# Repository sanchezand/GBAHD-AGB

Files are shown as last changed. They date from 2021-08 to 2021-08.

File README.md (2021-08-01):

# GBAHD-AGB Motherboard
This is a replacement AGB motherboard shield for the [gbaHD project](https://github.com/zwenergy/gbaHD).  
- The aim is to remove the CPU and RAM from an original AGB motherboard and place them in this new board.  
- Uses an MCU to connect a classic controller.  
- Has a cartridge slot with a switch to detect DMG/CGB games and switch voltages.
- Has a power switch circuitry to replace Spartan Edge switch.
- Has a better footprint for 3D printed cases

## Issues
- NOT TESTED YET
- Cart sensor switch might need to be changed
- Cart sensor switch footprint might be wrong.
- Clock might need to be rerouted.
- Link port might need to be rerouted
- No 3D printed case (yet)

## Contributing
I am **NOT** an electrical engineer. Take this as a hobby project from a software engineer's attempt at something cool. If you wish to contribute, see something wrong or want to add a feature please make a pull request or leave an issue!

## BOM
Add this later...

## Programming the MCU
**FIRMWARE NOT YET WRITTEN** (following instructions still work)

In order to program the MCU, you need an arduino to use as ISP.  
Use the following image to wire up an arduino to the board to program it.  
**I would also recomend not programming it while seated in the FPGA board.**
PCB Wireup  
After wiring the board, follow this tutorial to flash the bootloader and the sketch to the board.  
[ICSP Tutorial](https://www.arduino.cc/en/pmwiki.php?n=Tutorial/ArduinoISP)  
  
The Arduino code requires the [NintendoExtensionCtrl](https://github.com/dmadison/NintendoExtensionCtrl) library.

## Credits
This project would've not existed if it werent for people with real electrical engineering knowledge!
- ARCADETV - (Their AGB schematics seem to have dissapeared)
- Derek F - [GBA-2 Go](https://hackaday.io/project/169998-gba-2-go)
- Zwenergy - [GBAHD Creator](https://github.com/zwenergy/gbaHD)
- dmadison - [Nintendo Controller Libraries](https://github.com/dmadison/NintendoExtensionCtrl)

## Images
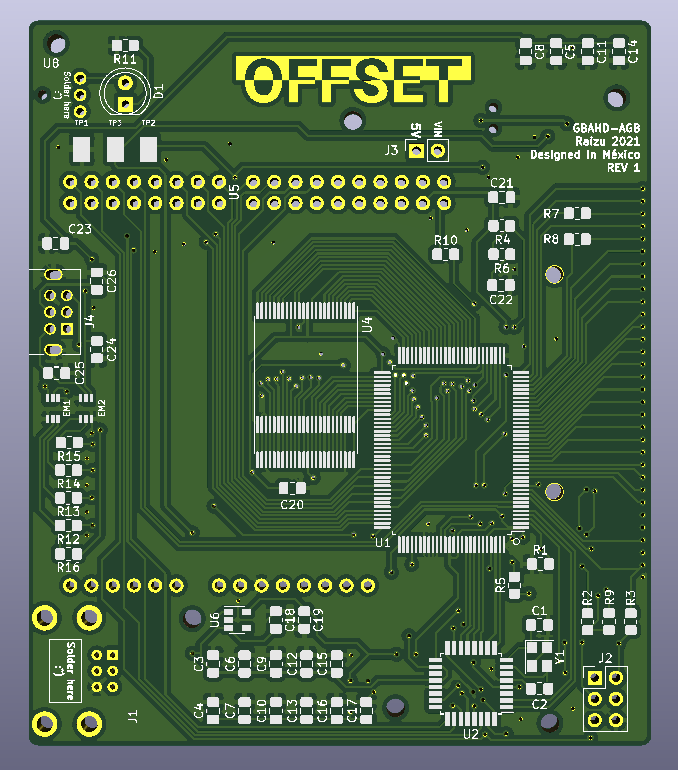
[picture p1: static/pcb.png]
PCB


## LICENSE
This documentation describes Open Hardware and is licensed under the CERN OHL v. 1.2.
You may redistribute and modify this documentation under the terms of the CERN OHL v.1.2. (http://ohwr.org/cernohl). This documentation is distributed WITHOUT ANY EXPRESS OR IMPLIED WARRANTY, INCLUDING OF MERCHANTABILITY, SATISFACTORY QUALITY AND FITNESS FOR A PARTICULAR PURPOSE. Please see the CERN OHL v.1.2 for applicable conditions.

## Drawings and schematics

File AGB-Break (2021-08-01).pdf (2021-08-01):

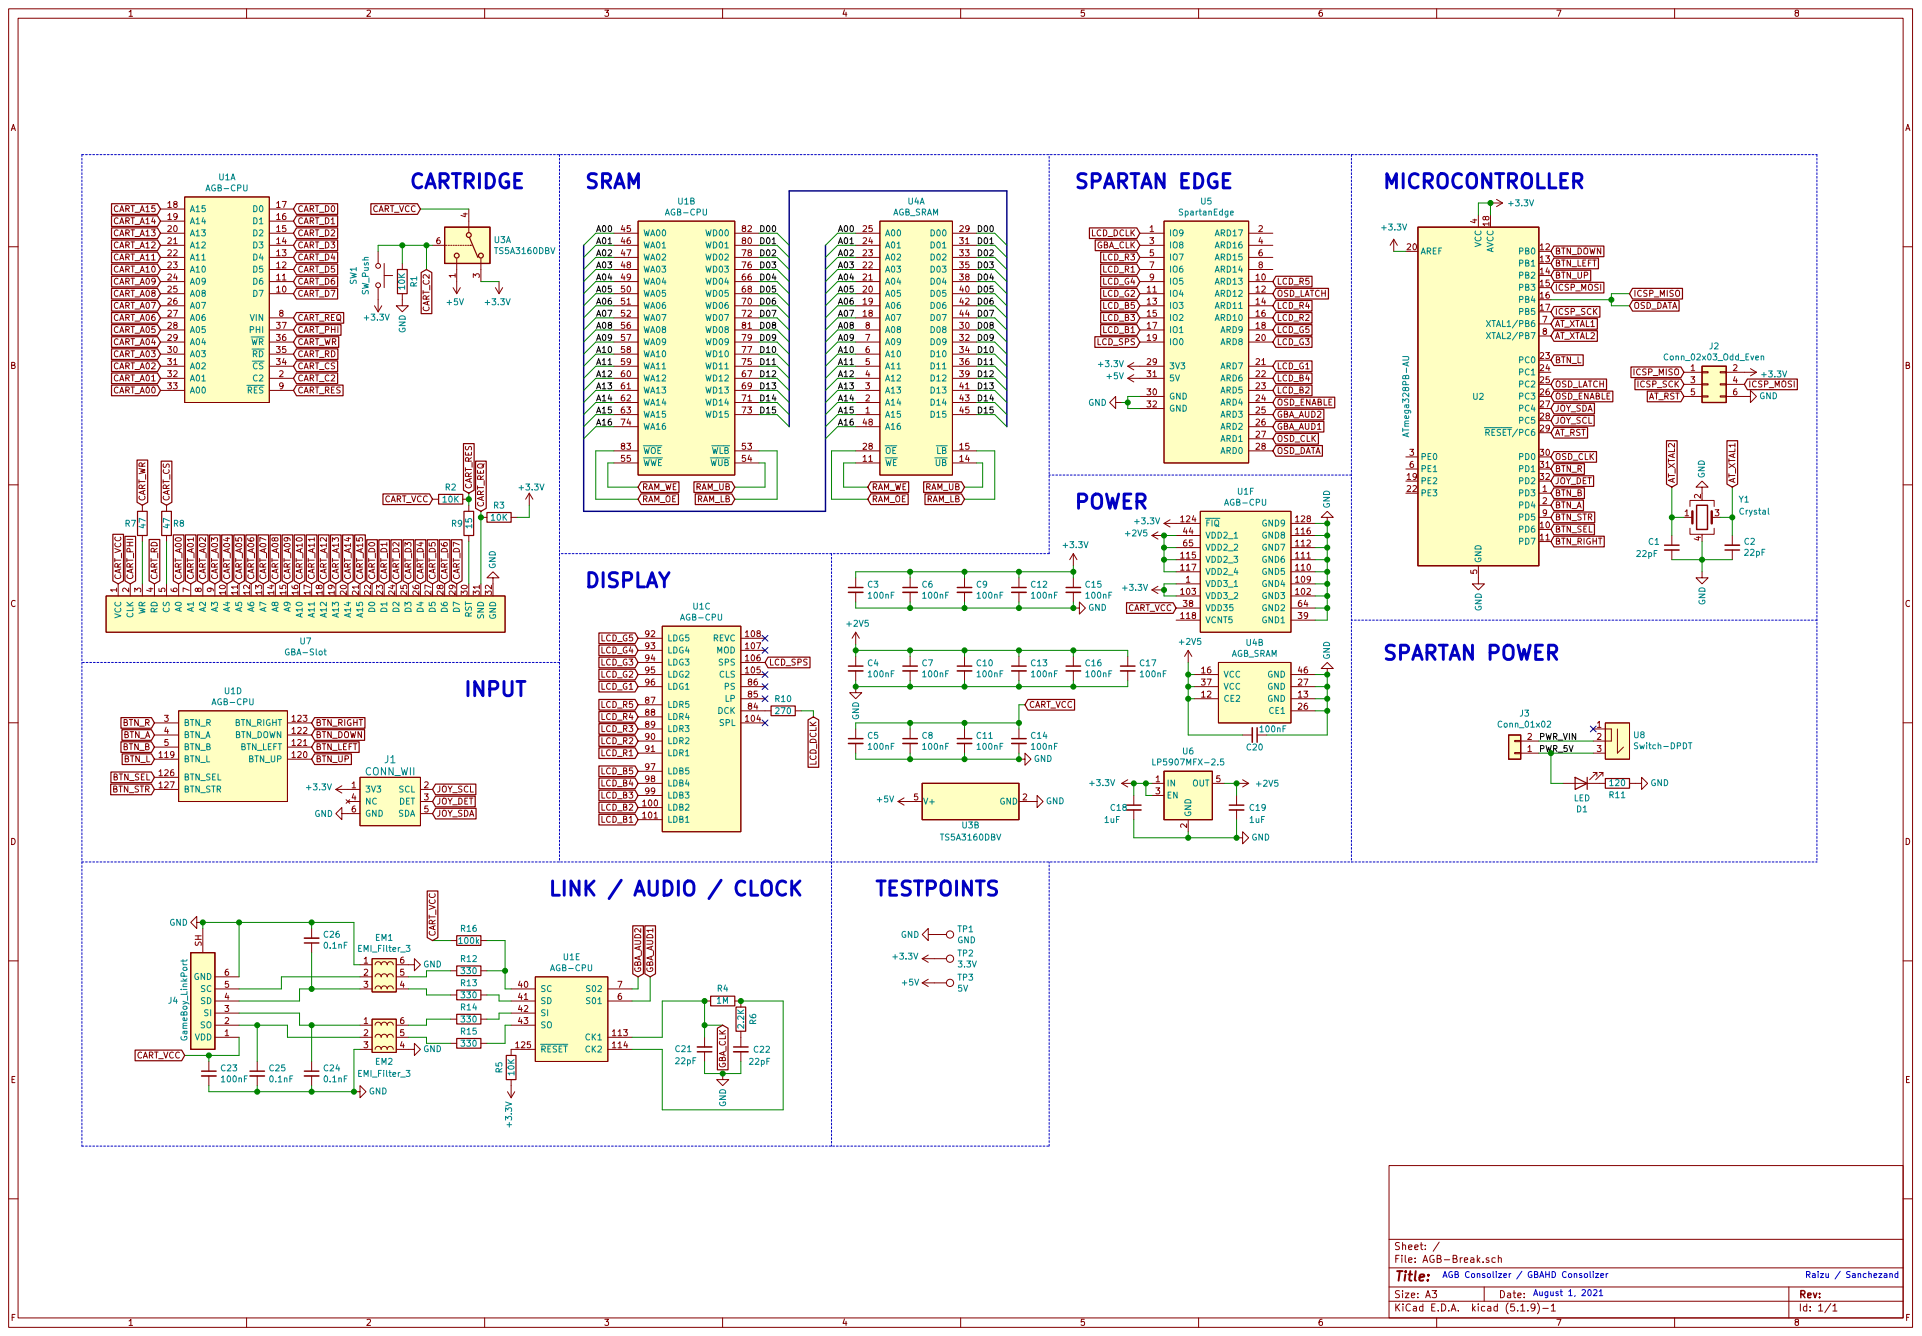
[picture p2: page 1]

9 U7 GBA-Slot VDD3_1 1 GND3 102 VDD3_2 103 GND4 109 GND5 110 GND6 111 GND7 112 VDD2_3 115 GND8 116 VDD2_4 117 VCNT5 118 FIQ 124 GND9 128 VDD35 38 GND1 39 VDD2_1 44 GND2 64 VDD2_2 65 U1F AGB-CPU

DISPLAY | | 100nF R3

3 RST 30 SND 31 GND 32 RD

Raizu / Sanchezand SPARTAN POWER

LINK / AUDIO / CLOCK | TESTPOINTS TP2 +3.3V 3.3V TP3 5V

2 | 5 R15

Id: 1/1 Title: File: AGB-Break.sch Sheet: /

AGB Consolizer / GBAHD Consolizer

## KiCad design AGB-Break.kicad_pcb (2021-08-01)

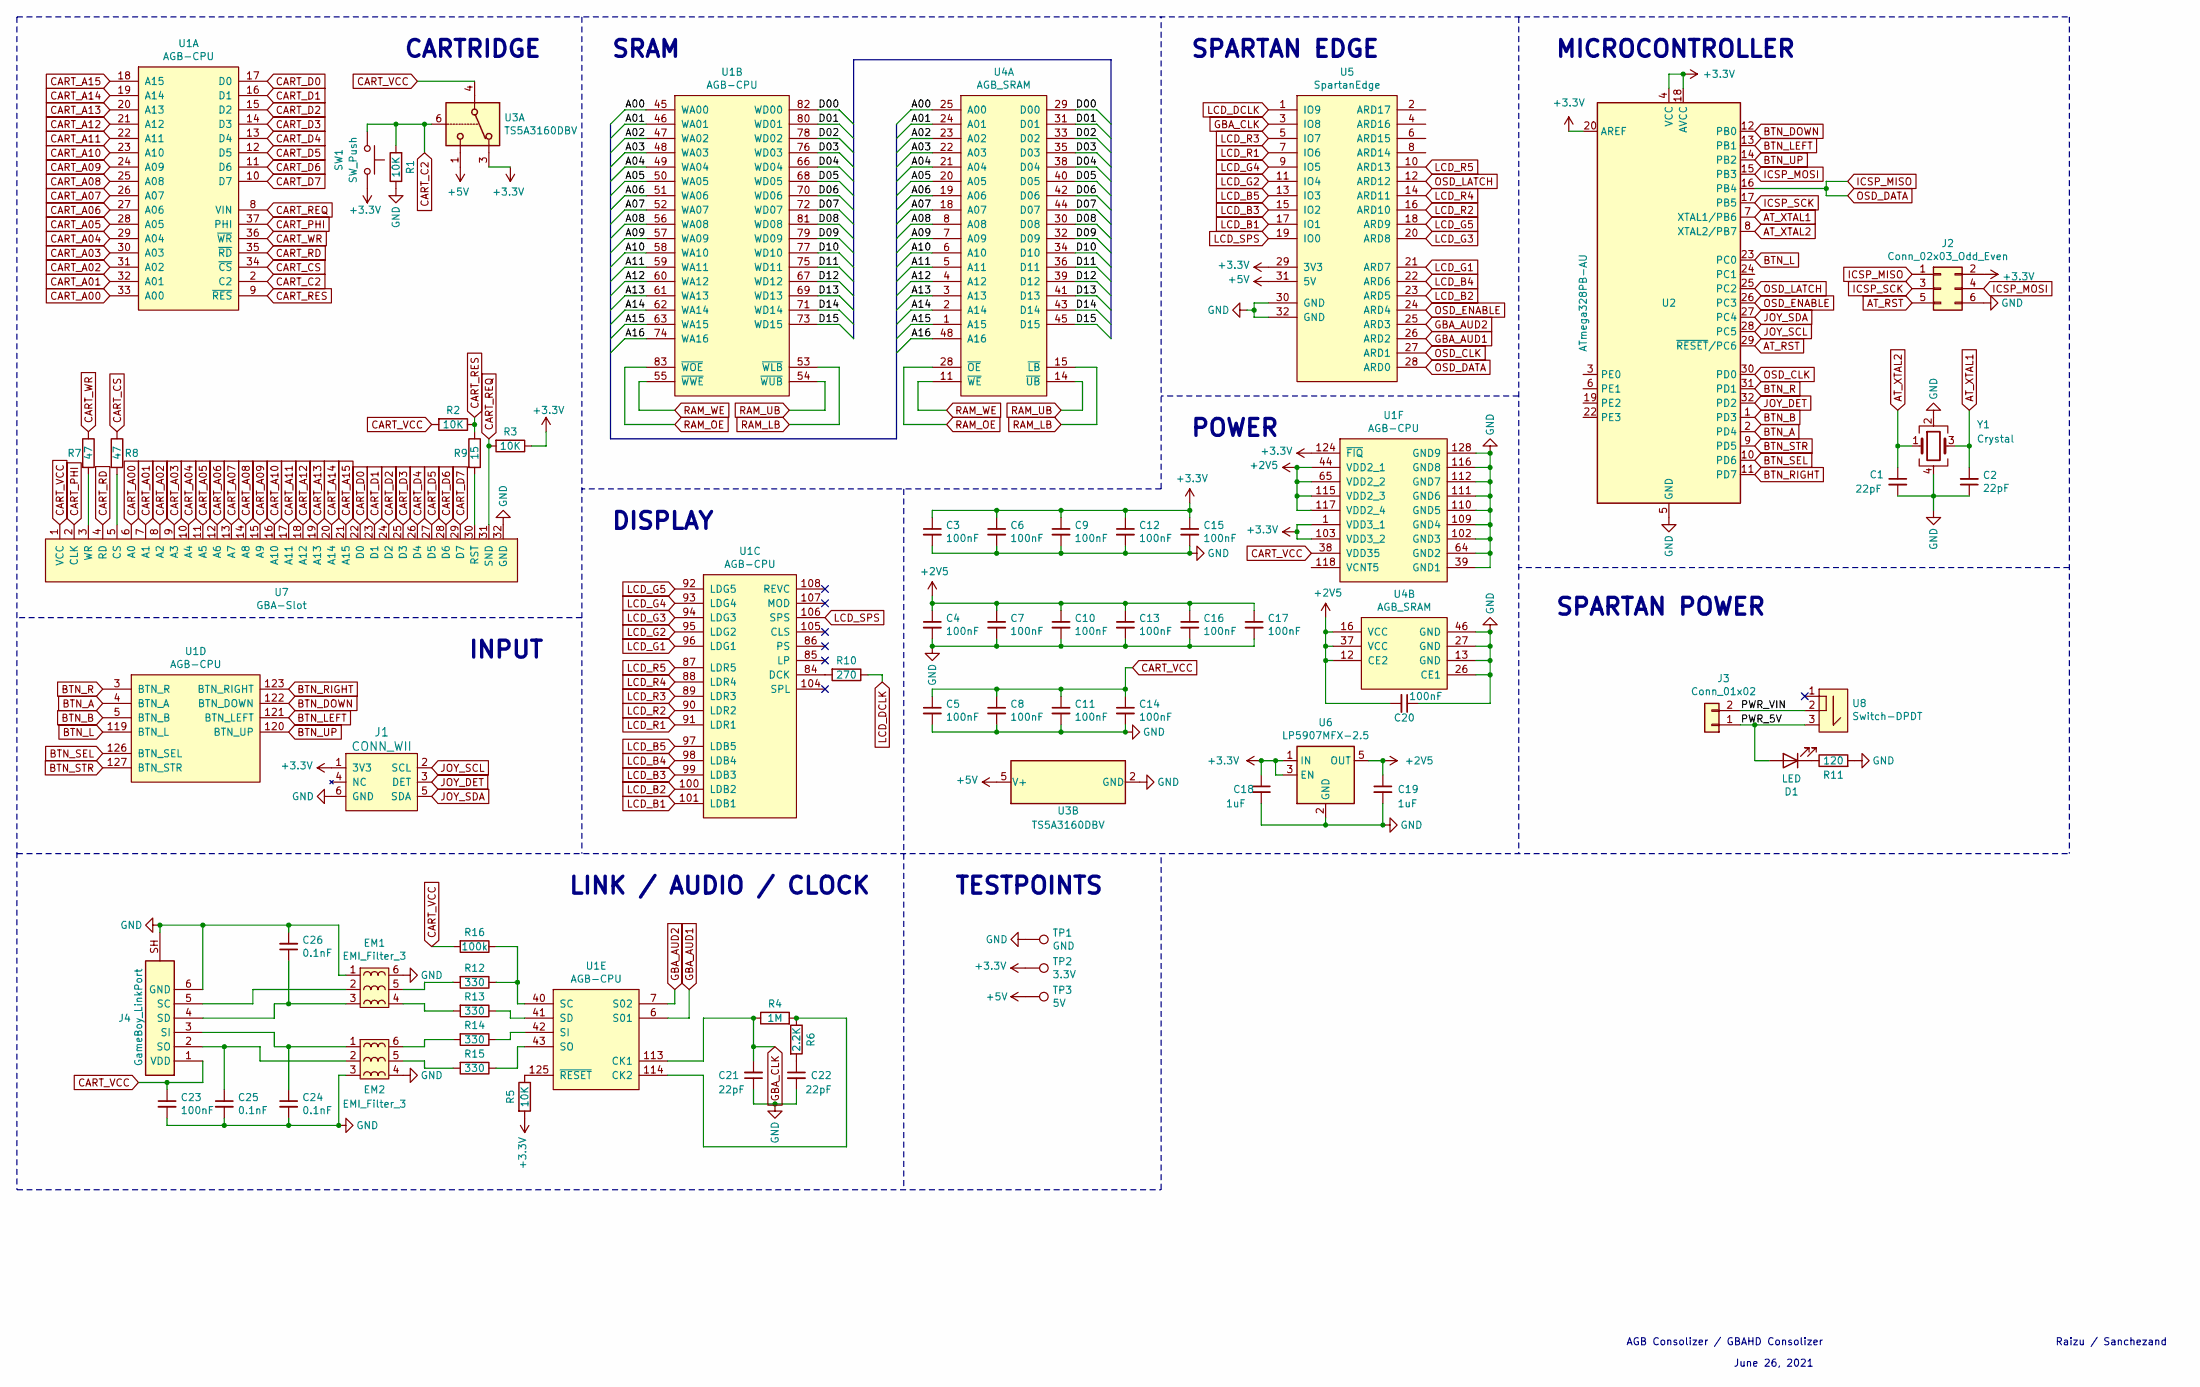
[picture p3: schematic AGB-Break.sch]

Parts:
C1, C2, C21, C22: 22pF; C_0805_2012Metric_Pad1.18x1.45mm_HandSolder
C3, C4, C5, C6, C7, C8, C9, C10, C11, C12, C13, C14, C15, C16, C17, C20, C23: 100nF; C_0805_2012Metric_Pad1.18x1.45mm_HandSolder
C18, C19: 1uF; C_0805_2012Metric_Pad1.18x1.45mm_HandSolder
C24, C25, C26: 0.1nF; C_0805_2012Metric_Pad1.18x1.45mm_HandSolder
D1: LED; LED_D5.0mm_FlatTop
EM1, EM2: EMI_Filter_3; Inductor-1008-3P
J1: CONN_WII
J2: Conn_02x03_Odd_Even; PinHeader_2x03_P2.54mm_Vertical
J3: Conn_01x02; PinSocket_1x02_P2.54mm_Vertical
J4: GameBoy_LinkPort; GameBoy_LinkPort_MGB_Horizontal
R1, R2, R3, R5: 10K; R_0805_2012Metric_Pad1.20x1.40mm_HandSolder
R4: 1M; R_0805_2012Metric_Pad1.20x1.40mm_HandSolder
R6: 2.2K; R_0805_2012Metric_Pad1.20x1.40mm_HandSolder
R7, R8: 47; R_0805_2012Metric_Pad1.20x1.40mm_HandSolder
R9: 15; R_0805_2012Metric_Pad1.20x1.40mm_HandSolder
R10: 270; R_0805_2012Metric_Pad1.20x1.40mm_HandSolder
R11: 120; R_0805_2012Metric_Pad1.20x1.40mm_HandSolder
R12, R13, R14, R15: 330; R_0805_2012Metric_Pad1.20x1.40mm_HandSolder
R16: 100k; R_0805_2012Metric_Pad1.20x1.40mm_HandSolder
SW1: SW_Push; Switch_K5-1617SA-01
TP1: GND; SOLDER_PAD
TP2: 3.3V; SOLDER_PAD
TP3: 5V; SOLDER_PAD
U1: AGB-CPU
U2: ATmega328PB-AU; TQFP-32_7x7mm_P0.8mm
U3: TS5A3160DBV; SOT-23-6
U4: AGB_SRAM
U5: SpartanEdge; SpartanEdge_Shield
U6: LP5907MFX-2.5; SOT-23-5
U7: GBA-Slot; GBA_CONNECTOR
U8: Switch-DPDT; XKB_XKB5858-Z-C
Y1: Crystal; Crystal_SMD_3225-4Pin_3.2x2.5mm

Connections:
+2V5: C4.1, C7.1, C10.1, C13.1, C16.1, C17.1, C19.1, C20.2, U1.44 (VDD2_1), U1.65 (VDD2_2), U1.115 (VDD2_3), U1.117 (VDD2_4), U4.12 (CE2), U4.16 (VCC), U4.37 (VCC), U6.5 (OUT)
+3V3: C3.1, C6.1, C9.1, C12.1, C15.1, C18.1, J1.1 (3V3), J2.2, R3.1, R5.2, SW1.2, TP2.1, U1.1 (VDD3_1), U1.103 (VDD3_2), U1.124 (~FIQ), U2.4 (VCC), U2.18 (AVCC), U2.20 (AREF), U3.3, U5.29 (3V3), U6.1 (IN), U6.3 (EN)
+5V: TP3.1, U3.1, U3.5 (V+), U5.31 (5V)
/A00: U1.45 (WA00), U4.25 (A00)
/A01: U1.46 (WA01), U4.24 (A01)
/A02: U1.47 (WA02), U4.23 (A02)
/A03: U1.48 (WA03), U4.22 (A03)
/A04: U1.49 (WA04), U4.21 (A04)
/A05: U1.50 (WA05), U4.20 (A05)
/A06: U1.51 (WA06), U4.19 (A06)
/A07: U1.52 (WA07), U4.18 (A07)
/A08: U1.56 (WA08), U4.8 (A08)
/A09: U1.57 (WA09), U4.7 (A09)
/A10: U1.58 (WA10), U4.6 (A10)
/A11: U1.59 (WA11), U4.5 (A11)
/A12: U1.60 (WA12), U4.4 (A12)
/A13: U1.61 (WA13), U4.3 (A13)
/A14: U1.62 (WA14), U4.2 (A14)
/A15: U1.63 (WA15), U4.1 (A15)
/A16: U1.74 (WA16), U4.48 (A16)
/D00: U1.82 (WD00), U4.29 (D00)
/D01: U1.80 (WD01), U4.31 (D01)
/D02: U1.78 (WD02), U4.33 (D02)
/D03: U1.76 (WD03), U4.35 (D03)
/D04: U1.66 (WD04), U4.38 (D04)
/D05: U1.68 (WD05), U4.40 (D05)
/D06: U1.70 (WD06), U4.42 (D06)
/D07: U1.72 (WD07), U4.44 (D07)
/D08: U1.81 (WD08), U4.30 (D08)
/D09: U1.79 (WD09), U4.32 (D09)
/D10: U1.77 (WD10), U4.34 (D10)
/D11: U1.75 (WD11), U4.36 (D11)
/D12: U1.67 (WD12), U4.39 (D12)
/D13: U1.69 (WD13), U4.41 (D13)
/D14: U1.71 (WD14), U4.43 (D14)
/D15: U1.73 (WD15), U4.45 (D15)
/PWR_5V: D1.2 (A), J3.1, U8.3
/PWR_VIN: J3.2, U8.2
AT_RST: J2.5, U2.29 (~RESET~/PC6)
AT_XTAL1: C2.2, U2.7 (XTAL1/PB6), Y1.3
AT_XTAL2: C1.1, U2.8 (XTAL2/PB7), Y1.1
BTN_A: U1.4 (BTN_A), U2.2 (PD4)
BTN_B: U1.5 (BTN_B), U2.1 (PD3)
BTN_DOWN: U1.122 (BTN_DOWN), U2.12 (PB0)
BTN_L: U1.119 (BTN_L), U2.23 (PC0)
BTN_LEFT: U1.121 (BTN_LEFT), U2.13 (PB1)
BTN_R: U1.3 (BTN_R), U2.31 (PD1)
BTN_RIGHT: U1.123 (BTN_RIGHT), U2.11 (PD7)
BTN_SEL: U1.126 (BTN_SEL), U2.10 (PD6)
BTN_STR: U1.127 (BTN_STR), U2.9 (PD5)
BTN_UP: U1.120 (BTN_UP), U2.14 (PB2)
CART_A00: U1.33 (A00), U7.6 (A0)
CART_A01: U1.32 (A01), U7.7 (A1)
CART_A02: U1.31 (A02), U7.8 (A2)
CART_A03: U1.30 (A03), U7.9 (A3)
CART_A04: U1.29 (A04), U7.10 (A4)
CART_A05: U1.28 (A05), U7.11 (A5)
CART_A06: U1.27 (A06), U7.12 (A6)
CART_A07: U1.26 (A07), U7.13 (A7)
CART_A08: U1.25 (A08), U7.14 (A8)
CART_A09: U1.24 (A09), U7.15 (A9)
CART_A10: U1.23 (A10), U7.16 (A10)
CART_A11: U1.22 (A11), U7.17 (A11)
CART_A12: U1.21 (A12), U7.18 (A12)
CART_A13: U1.20 (A13), U7.19 (A13)
CART_A14: U1.19 (A14), U7.20 (A14)
CART_A15: U1.18 (A15), U7.21 (A15)
CART_C2: R1.2, SW1.1, U1.2 (C2), U3.6
CART_CS: R8.1, U1.34 (~CS)
CART_D0: U1.17 (D0), U7.22 (D0)
CART_D1: U1.16 (D1), U7.23 (D1)
CART_D2: U1.15 (D2), U7.24 (D2)
CART_D3: U1.14 (D3), U7.25 (D3)
CART_D4: U1.13 (D4), U7.26 (D4)
CART_D5: U1.12 (D5), U7.27 (D5)
CART_D6: U1.11 (D6), U7.28 (D6)
CART_D7: U1.10 (D7), U7.29 (D7)
CART_PHI: U1.37 (PHI), U7.2 (CLK~)
CART_RD: U1.35 (~RD), U7.4 (RD)
CART_REQ: R3.2, U1.8 (VIN), U7.31 (SND)
CART_RES: R2.1, R9.1, U1.9 (~RES)
CART_VCC: C5.1, C8.1, C11.1, C14.1, C23.1, J4.1 (VDD), R2.2, R16.2, U1.38 (VDD35), U3.4, U7.1 (VCC)
CART_WR: R7.1, U1.36 (~WR)
GBA_AUD1: U1.6 (S01), U5.26 (ARD2)
GBA_AUD2: U1.7 (S02), U5.25 (ARD3)
GBA_CLK: C21.2, R4.1, U1.113 (CK1), U5.3 (IO8)
GND: C1.2, C2.1, C3.2, C4.2, C5.2, C6.2, C7.2, C8.2, C9.2, C10.2, C11.2, C12.2, C13.2, C14.2, C15.2, C16.2, C17.2, C18.2, C19.2, C20.1, C21.1, C22.2, C23.2, C24.2, C25.2, C26.2, EM1.1, EM1.6, EM2.3, EM2.4, J1.6 (GND), J2.6, J4.6 (GND), J4.SH, R1.1, R11.2, TP1.1, U1.39 (GND1), U1.64 (GND2), U1.102 (GND3), U1.109 (GND4), U1.110 (GND5), U1.111 (GND6), U1.112 (GND7), U1.116 (GND8), U1.128 (GND9), U2.5 (GND), U2.21 (GND), U3.2 (GND), U4.13 (GND), U4.26 (CE1), U4.27 (GND), U4.46 (GND), U5.30 (GND), U5.32 (GND), U6.2 (GND), U7.32 (GND), Y1.2, Y1.4
ICSP_MISO: J2.1, U2.16 (PB4), U5.28 (ARD0)
ICSP_MOSI: J2.4, U2.15 (PB3)
ICSP_SCK: J2.3, U2.17 (PB5)
JOY_DET: J1.3 (DET), U2.32 (PD2)
JOY_SCL: J1.2 (SCL), U2.28 (PC5)
JOY_SDA: J1.5 (SDA), U2.27 (PC4)
LCD_B1: U1.101 (LDB1), U5.17 (IO1)
LCD_B2: U1.100 (LDB2), U5.23 (ARD5)
LCD_B3: U1.99 (LDB3), U5.15 (IO2)
LCD_B4: U1.98 (LDB4), U5.22 (ARD6)
LCD_B5: U1.97 (LDB5), U5.13 (IO3)
LCD_DCLK: R10.1, U5.1 (IO9)
LCD_G1: U1.96 (LDG1), U5.21 (ARD7)
LCD_G2: U1.95 (LDG2), U5.11 (IO4)
LCD_G3: U1.94 (LDG3), U5.20 (ARD8)
LCD_G4: U1.93 (LDG4), U5.9 (IO5)
LCD_G5: U1.92 (LDG5), U5.18 (ARD9)
LCD_R1: U1.91 (LDR1), U5.7 (IO6)
LCD_R2: U1.90 (LDR2), U5.16 (ARD10)
LCD_R3: U1.89 (LDR3), U5.5 (IO7)
LCD_R4: U1.88 (LDR4), U5.14 (ARD11)
LCD_R5: U1.87 (LDR5), U5.10 (ARD13)
LCD_SPS: U1.106 (SPS), U5.19 (IO0)
unnamed: C22.1, R6.2
unnamed: C24.1, EM2.1, J4.3 (SI)
unnamed: C25.1, EM2.2, J4.2 (SO)
unnamed: C26.1, EM1.3, J4.4 (SD)
unnamed: D1.1 (K), R11.1
unnamed: EM1.2, J4.5 (SC)
unnamed: EM1.4, R13.2
unnamed: EM1.5, R12.2
unnamed: EM2.5, R15.2
unnamed: EM2.6, R14.2
unnamed: R4.2, R6.1, U1.114 (CK2)
unnamed: R5.1, U1.125 (~RESET)
unnamed: R7.2, U7.3 (WR)
unnamed: R8.2, U7.5 (CS)
unnamed: R9.2, U7.30 (RST)
unnamed: R10.2, U1.84 (DCK)
unnamed: R12.1, R16.1, U1.40 (SC)
unnamed: R13.1, U1.41 (SD)
unnamed: R14.1, U1.42 (SI)
unnamed: R15.1, U1.43 (SO)
OSD_CLK: U2.30 (PD0), U5.27 (ARD1)
OSD_ENABLE: U2.26 (PC3), U5.24 (ARD4)
OSD_LATCH: U2.25 (PC2), U5.12 (ARD12)
RAM_LB: U1.53 (~WLB), U4.15 (~LB)
RAM_OE: U1.83 (~WOE), U4.28 (~OE)
RAM_UB: U1.54 (~WUB), U4.14 (~UB)
RAM_WE: U1.55 (~WWE), U4.11 (~WE)

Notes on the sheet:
CARTRIDGE
AGB Consolizer / GBAHD Consolizer
June 26, 2021
Raizu / Sanchezand
SRAM
SPARTAN EDGE
POWER
DISPLAY
INPUT
MICROCONTROLLER
SPARTAN POWER
LINK / AUDIO / CLOCK
TESTPOINTS

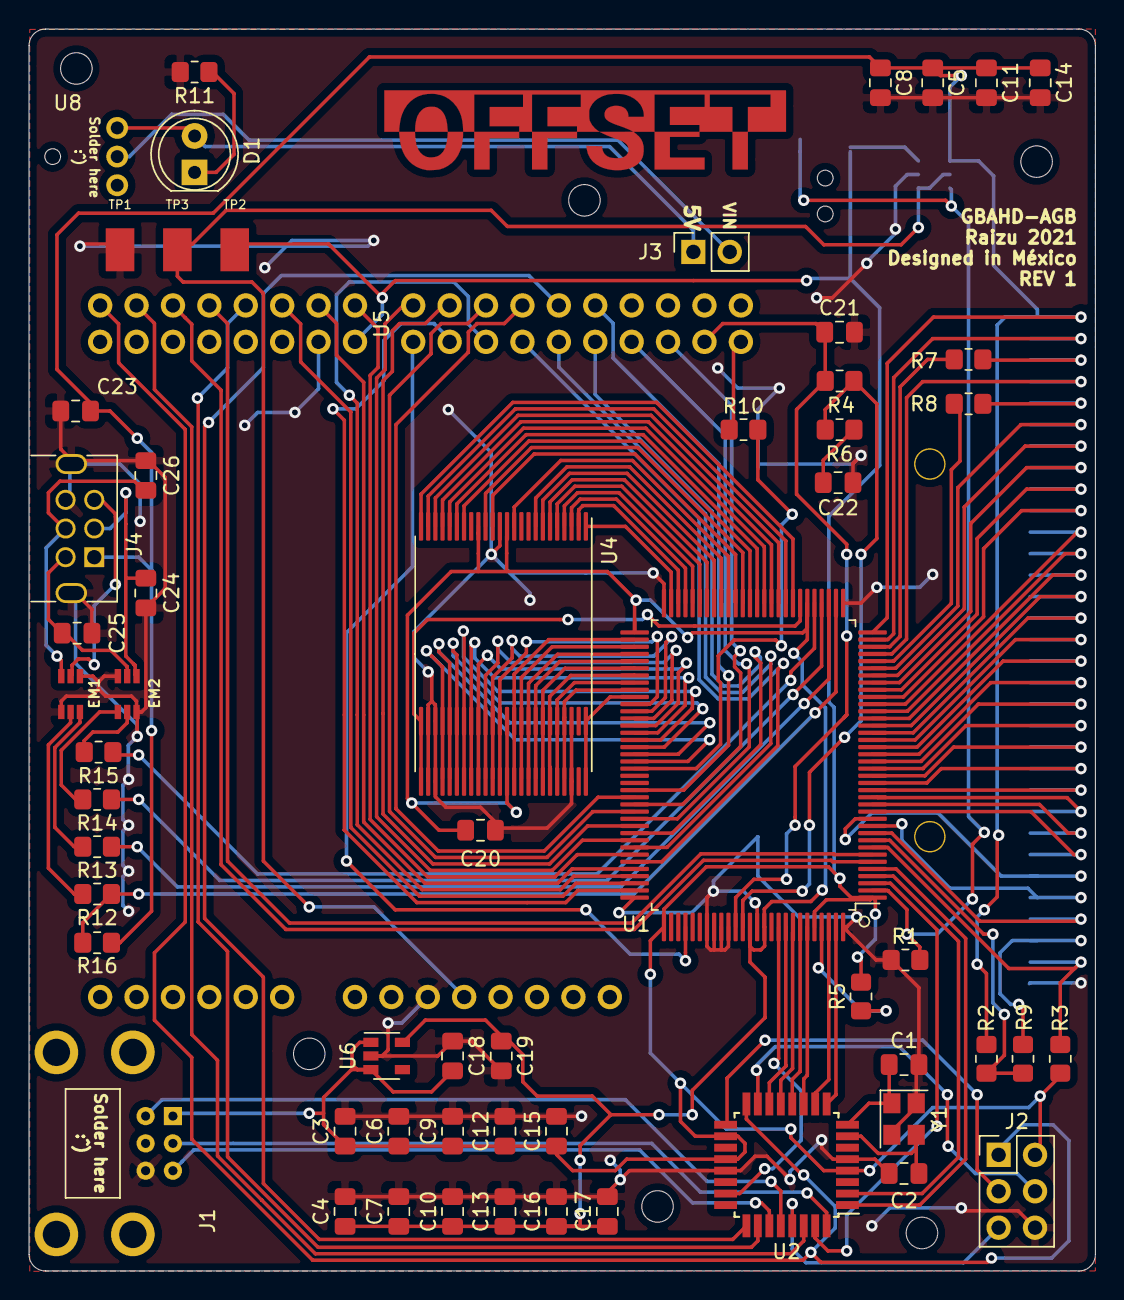
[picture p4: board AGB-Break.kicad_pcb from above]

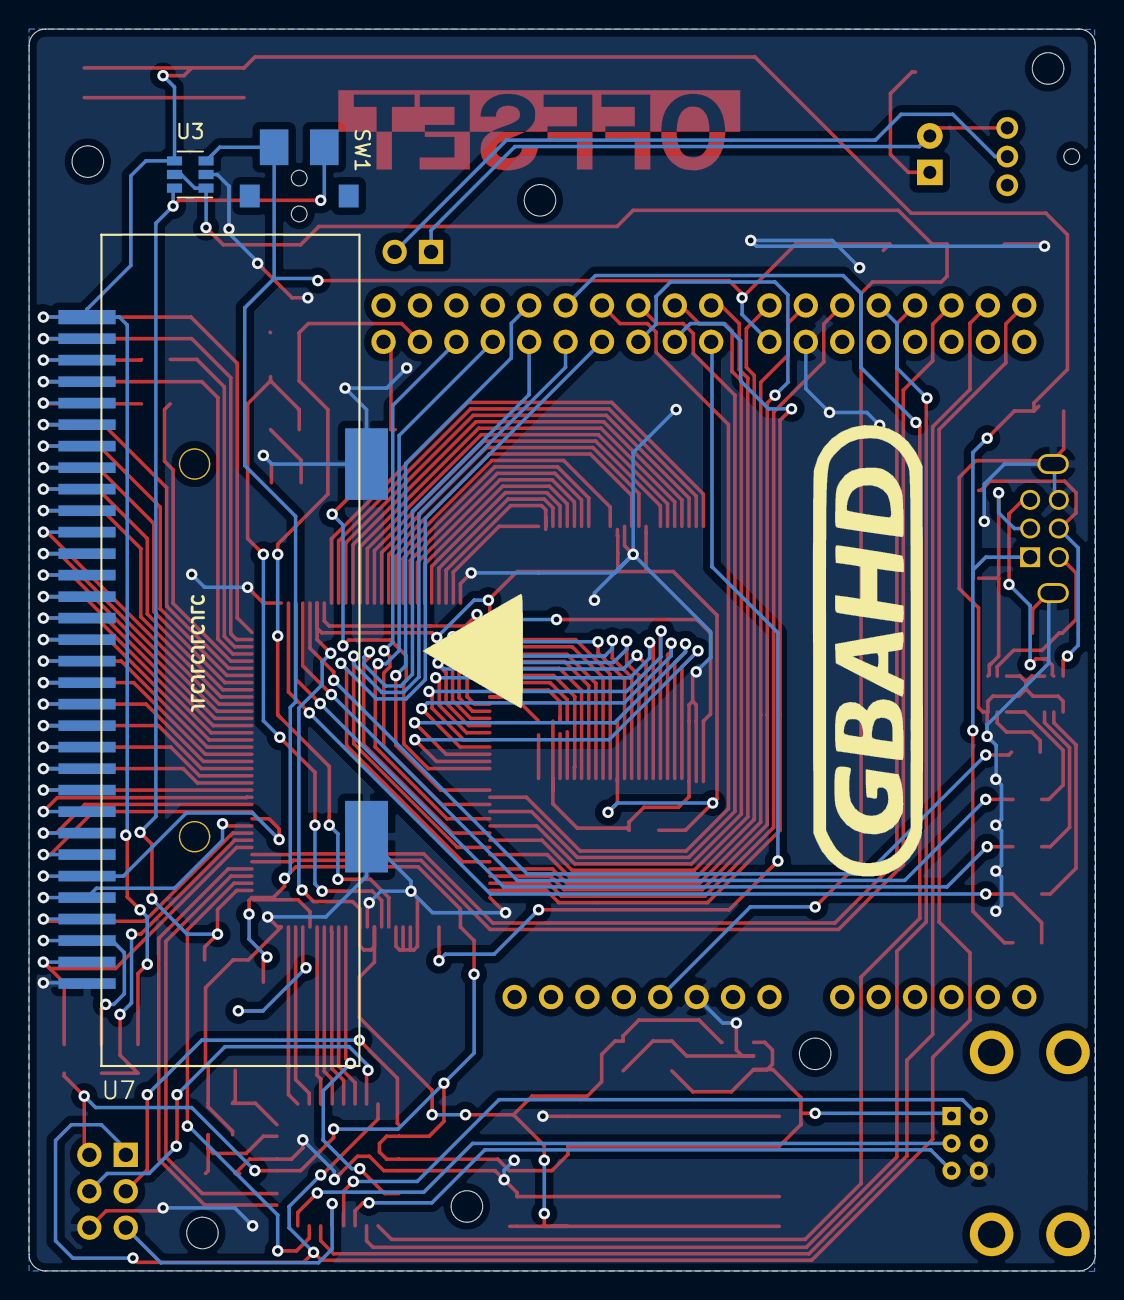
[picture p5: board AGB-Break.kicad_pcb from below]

Board: 2 copper layers, 74.4 x 86.7 mm, 62 parts (4 on the bottom side), 137 nets.

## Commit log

2021-06-28 Initial commit, not done yet.
    [AGB-Break.kicad_pcb, AGB-Break.sch, AGB-Break_OLD.sch]
2021-07-01 Finished current routing, still missing power switch.
    [AGB-Break.kicad_pcb, AGB-Break.sch]
2021-07-02 Finished PCB v1
    [AGB-Break.kicad_pcb, AGB-Break.sch]
2021-07-07 Finished PCB work, but headers are flipped, need to fix this :(
    [AGB-Break.kicad_pcb, AGB-Break.sch]
2021-07-08 Finished PCB layout, sent to pcb fab.
    [AGB-Break.kicad_pcb, AGB-Break.sch]
2021-08-01 Changed clock wiring
    [AGB-Break.kicad_pcb, AGB-Break.sch]
2021-08-01 Added PDF schematic
    [AGB-Break.sch]
